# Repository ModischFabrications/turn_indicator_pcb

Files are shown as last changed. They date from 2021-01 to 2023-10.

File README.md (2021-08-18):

# turn_indicator_pcb

This is the PCB for [Turn Indicator](https://github.com/ModischFabrications/Turn_Indicator).

Open like regular in KiCad. Look into the docs zip under [Actions/KiCad Exports](https://github.com/ModischFabrications/turn_indicator_pcb/actions/workflows/exports.yml) to see renderings. 

This schematic is meant to be soldered manually onto a perfboard, but feel free to order a PCB instead. 

## Decisions

Size is determined by a generic 4x6 cm perfboard. 

### Electrical
Button panel connectors are grouped in pairs of 4 because my JST-XH set only has 2..5 pins. 
Grouping by input/output was the obvious choice,even if they are crossed at the buttons. 

Supply is a 18650 in a supply board, which means that grounding is useless. Using the bicylce frame as common ground could have been simple, but it's not worth the risk if there are 4+ wires routed anyways. 

Short-circuit-resistance of the power leads is archieved using a polyfuse. Resistance of the inputs is build-in, as they are high impedance, but the outputs are at risk. 

Introducing series resistances into every single connection could have made it safer, but I can't be arsed at the moment. Active-Low or High doesn't really matter either, a cross between adjacent leads would result in one overloading regardless. Feel free to insert ~300 ohm everywhere if you want to be safe. 

Sharing Clocks for the LED-stripes is technically possible, but a lot more work. Separate Pins, as seen here, is way easier.

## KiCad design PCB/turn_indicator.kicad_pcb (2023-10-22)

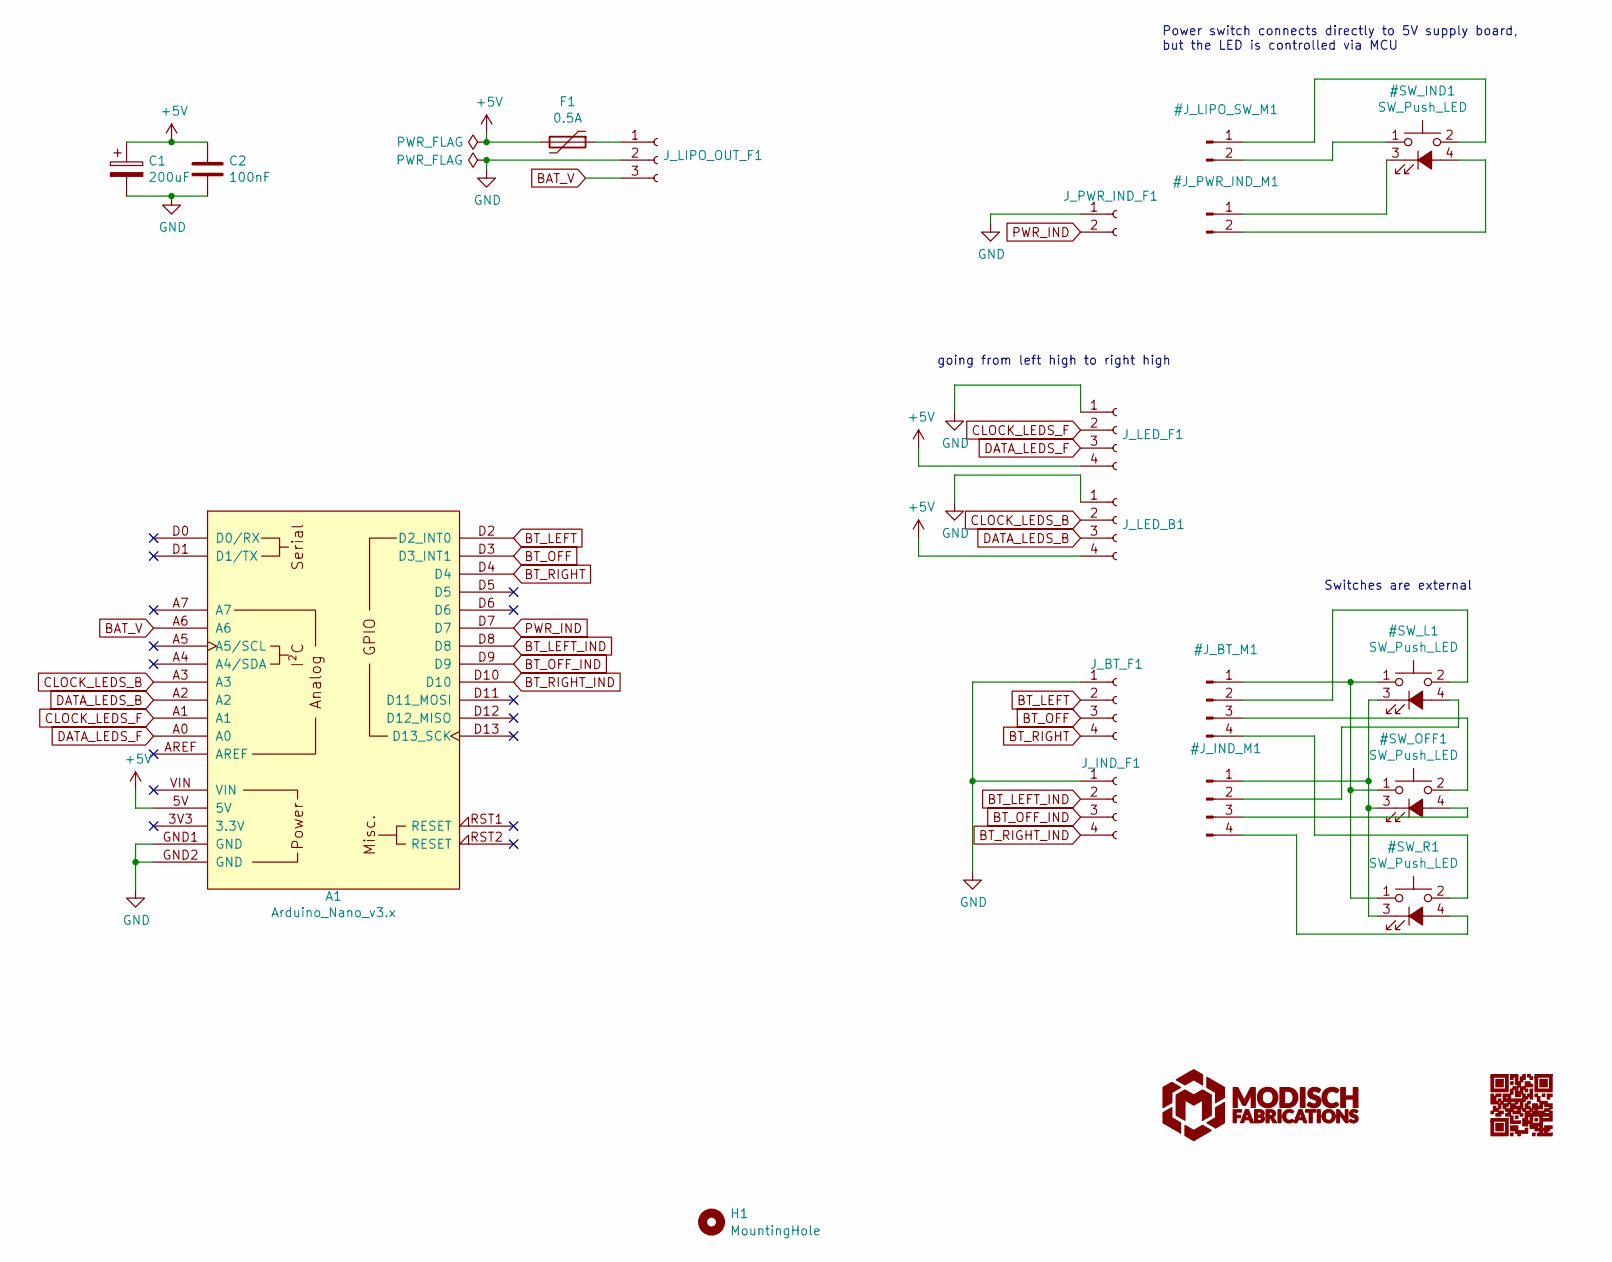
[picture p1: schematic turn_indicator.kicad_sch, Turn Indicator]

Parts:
A1: Arduino_Nano_v3.x; Arduino_Nano_Socket
C1: 200uF; CP_Radial_D8.0mm_P2.50mm
C2: 100nF; C_0603_1608Metric
F1: 0.5A; Fuse_1206_3216Metric_Pad1.42x1.75mm_HandSolder
H1: MountingHole; MountingHole_3.2mm_M3
J_BT_F1: Conn_01x04_Socket; JST_XH_B4B-XH-A_1x04_P2.50mm_Vertical
J_IND_F1: Conn_01x04_Socket; JST_XH_B4B-XH-A_1x04_P2.50mm_Vertical
J_LED_B1: Conn_01x04_Socket; JST_XH_B4B-XH-A_1x04_P2.50mm_Vertical
J_LED_F1: Conn_01x04_Socket; JST_XH_B4B-XH-A_1x04_P2.50mm_Vertical
J_LIPO_OUT_F1: Conn_01x03_Socket; JST_XH_B3B-XH-A_1x03_P2.50mm_Vertical
J_PWR_IND_F1: Conn_01x02_Socket; JST_XH_B2B-XH-A_1x02_P2.50mm_Vertical

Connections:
+5V: A1.5V, C1.1, C2.1, F1.2, J_LED_B1.4, J_LED_F1.4
BAT_V: A1.A6, J_LIPO_OUT_F1.3
BT_LEFT: A1.D2 (D2_INT0), J_BT_F1.2
BT_LEFT_IND: A1.D8, J_IND_F1.2
BT_OFF: A1.D3 (D3_INT1), J_BT_F1.3
BT_OFF_IND: A1.D9, J_IND_F1.3
BT_RIGHT: A1.D4, J_BT_F1.4
BT_RIGHT_IND: A1.D10, J_IND_F1.4
CLOCK_LEDS_B: A1.A3, J_LED_B1.2
CLOCK_LEDS_F: A1.A1, J_LED_F1.2
DATA_LEDS_B: A1.A2, J_LED_B1.3
DATA_LEDS_F: A1.A0, J_LED_F1.3
GND: A1.GND1 (GND), A1.GND2 (GND), C1.2, C2.2, J_BT_F1.1, J_IND_F1.1, J_LED_B1.1, J_LED_F1.1, J_LIPO_OUT_F1.2, J_PWR_IND_F1.1
unnamed: F1.1, J_LIPO_OUT_F1.1
PWR_IND: A1.D7, J_PWR_IND_F1.2

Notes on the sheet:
going from left high to right high
Switches are external
Power switch connects directly to 5V supply board, but the LED is controlled via MCU

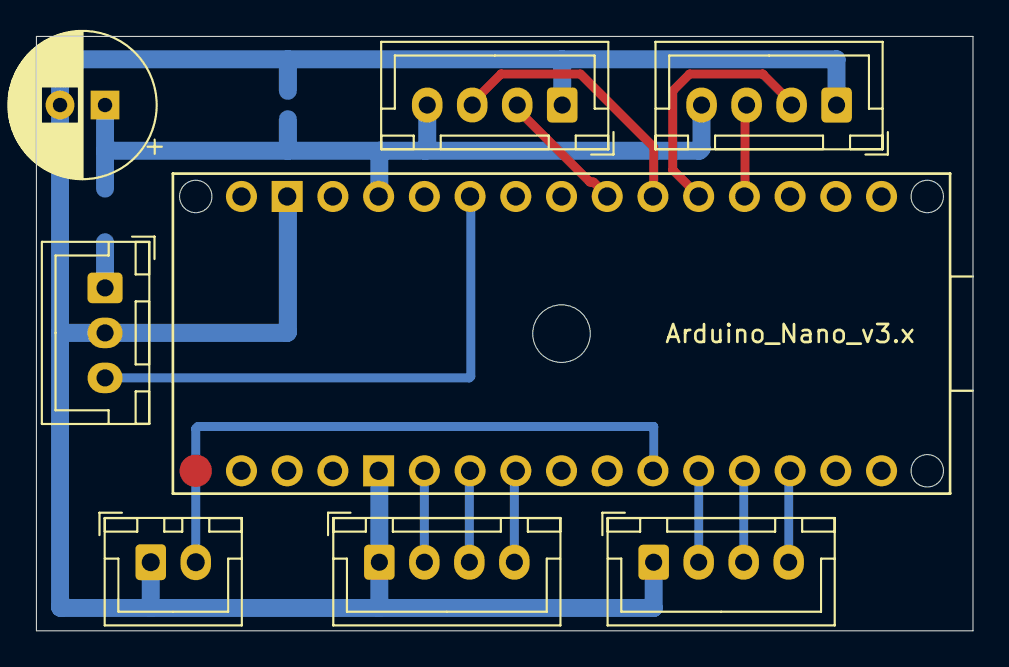
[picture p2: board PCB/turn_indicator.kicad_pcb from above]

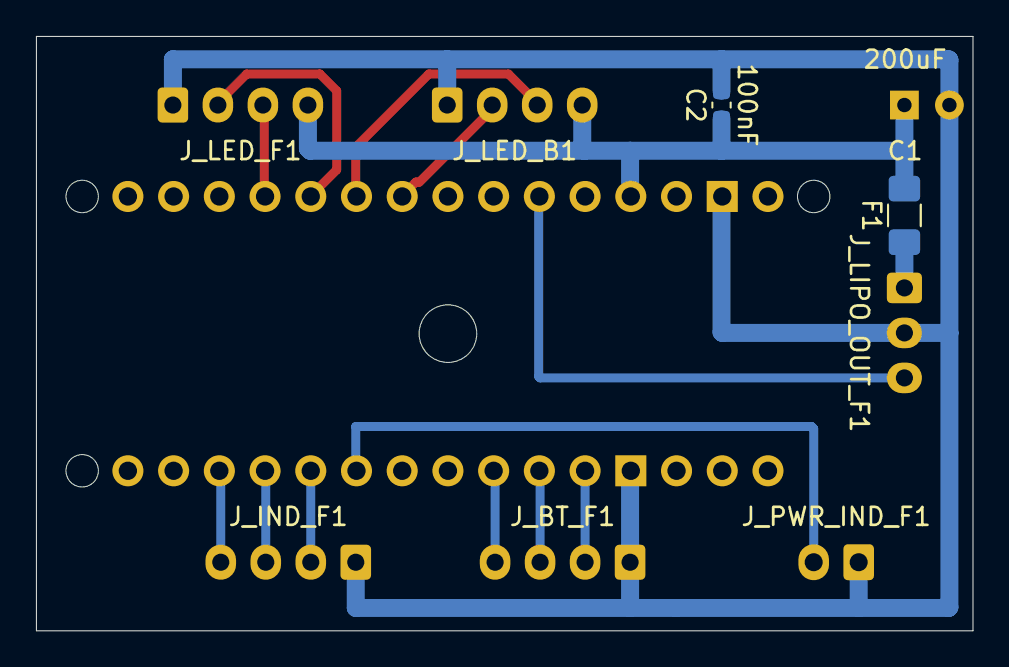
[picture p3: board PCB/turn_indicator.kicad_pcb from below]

Board: 2 copper layers, 52.0 x 33.0 mm, 11 parts (2 on the bottom side), 15 nets.

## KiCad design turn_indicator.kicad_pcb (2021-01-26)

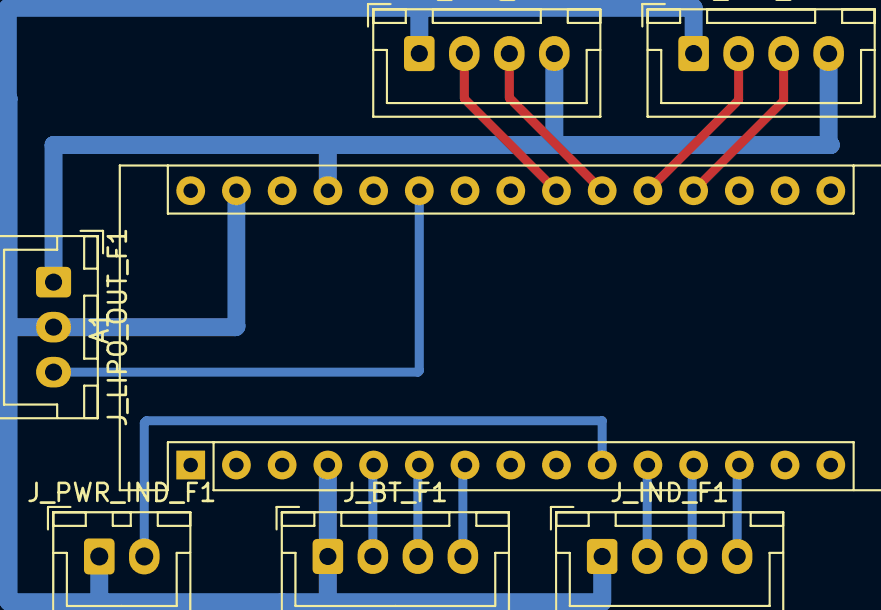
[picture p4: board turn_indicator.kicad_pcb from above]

Board: 2 copper layers, 7 parts (0 on the bottom side), 14 nets.

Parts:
A1: Arduino_Nano_v3.x; Arduino_Nano
J_BT_F1: Conn_01x04_Female; JST_XH_B4B-XH-A_1x04_P2.50mm_Vertical
J_IND_F1: Conn_01x04_Female; JST_XH_B4B-XH-A_1x04_P2.50mm_Vertical
J_LED_L1: Conn_01x04_Female; JST_XH_B4B-XH-A_1x04_P2.50mm_Vertical
J_LED_R1: Conn_01x04_Female; JST_XH_B4B-XH-A_1x04_P2.50mm_Vertical
J_LIPO_OUT_F1: Conn_01x03_Female; JST_XH_B3B-XH-A_1x03_P2.50mm_Vertical
J_PWR_IND_F1: Conn_01x02_Female; JST_XH_B2B-XH-A_1x02_P2.50mm_Vertical

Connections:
+5V: A1.27, J_LED_L1.4, J_LED_R1.4, J_LIPO_OUT_F1.1
BAT_V: A1.25, J_LIPO_OUT_F1.3
BT_L: A1.5, J_BT_F1.2
BT_L_IND: A1.11, J_IND_F1.2
BT_OFF: A1.6, J_BT_F1.3
BT_OFF_IND: A1.12, J_IND_F1.3
BT_RIGHT: A1.7, J_BT_F1.4
BT_RIGHT_IND: A1.13, J_IND_F1.4
CLOCK_LEDS_L: A1.20, J_LED_L1.2
CLOCK_LEDS_R: A1.22, J_LED_R1.2
DATA_LEDS_L: A1.19, J_LED_L1.3
DATA_LEDS_R: A1.21, J_LED_R1.3
GND: A1.4, A1.29, J_BT_F1.1, J_IND_F1.1, J_LED_L1.1, J_LED_R1.1, J_LIPO_OUT_F1.2, J_PWR_IND_F1.1
PWR_IND: A1.10, J_PWR_IND_F1.2

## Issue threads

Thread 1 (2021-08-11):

Refine automatic Exports

ModischFabrications, 2021-08-11:
No idea how it works yet, but it would be nice to use it. Look into https://github.com/nerdyscout/kicad-exports/issues/27 for some hints.

https://github.com/nerdyscout/kicad-exports/blob/main/config/bundle/fabrication.jlcpcb.kibot.lst

ModischFabrications, 2021-08-11:
1. Check rough file existence
2. Check DRC, ERC, ...
3. build pretty images
4. build gerber export for pcb manufacturing

ModischFabrications, 2021-08-11:
Filter out trash that is unused, see https://github.com/nerdyscout/kicad-exports/issues/30

ModischFabrications, 2021-08-11:
Retention is limited to 90 days, which would render image links dead after a while. Too bad...

nerdyscout, 2021-08-28:
> Linking image files into the readme would be the gold standard, see if that's possible.

unfortunately yes... that is why I, eg for schematics, create svg files and push those into the a separate branch of the repository.

Closed 2023-10-22.

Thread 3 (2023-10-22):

Create proper PCB layout

ModischFabrications, 2023-10-22:
Current layout is just for perfboard soldering.
 A great thing would be "board variants" or something similar with a 1:n mapping, but I can live without perfboard files if there is no other way.

Remember to re-enable DRC in kibot.yaml in that case, see 2c3c816

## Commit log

2021-01-26 init and v1
    [turn_indicator.kicad_pcb, turn_indicator.sch]
2021-08-11 pcb subfolder and unknown pending changes
    [turn_indicator.kicad_pcb, turn_indicator.sch]
2021-08-11 shrink to 5x7 perfboard, add comments, add fuse and capacitors
    [turn_indicator.kicad_pcb, turn_indicator.sch]
2023-10-22 migrate to kicad 6, add gh actions from easylight
    [turn_indicator.kicad_pcb, turn_indicator.kicad_sch]
2023-10-22 update to kicad 7, increase fuse size to proper 1206, cleanup PCB, include QR code and MF logo
    [turn_indicator.kicad_pcb, turn_indicator.kicad_sch]
2023-10-22 remove migration cache, allow DRC to fail
    [turn_indicator.sch]
